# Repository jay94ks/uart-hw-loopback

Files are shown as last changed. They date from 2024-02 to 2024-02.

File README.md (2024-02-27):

## UART hardware loopback.
This hardware causes `UART` to loop back at the hardware level.
Developed based on the `STM32F042` and `CH340` chips, 
it taps the serial communication of the target software 
using the `baud-rate` auto-negotiation function of `VCP`.

In addition, since the pins of the 'SL2.1A' chip are left, 
so I added the USB hub function to utilize them.
and 'PD (Power Delivery)' input in case the current is insufficient.

### Hardware:
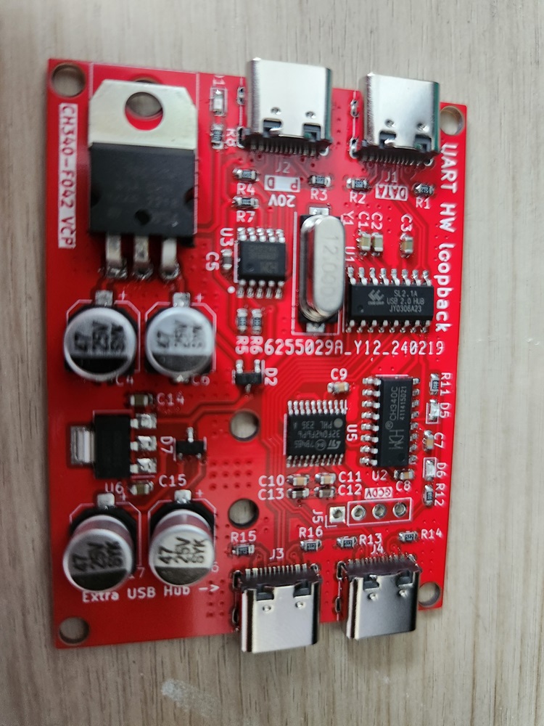
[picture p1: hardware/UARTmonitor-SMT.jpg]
Hardware


### Schematic:
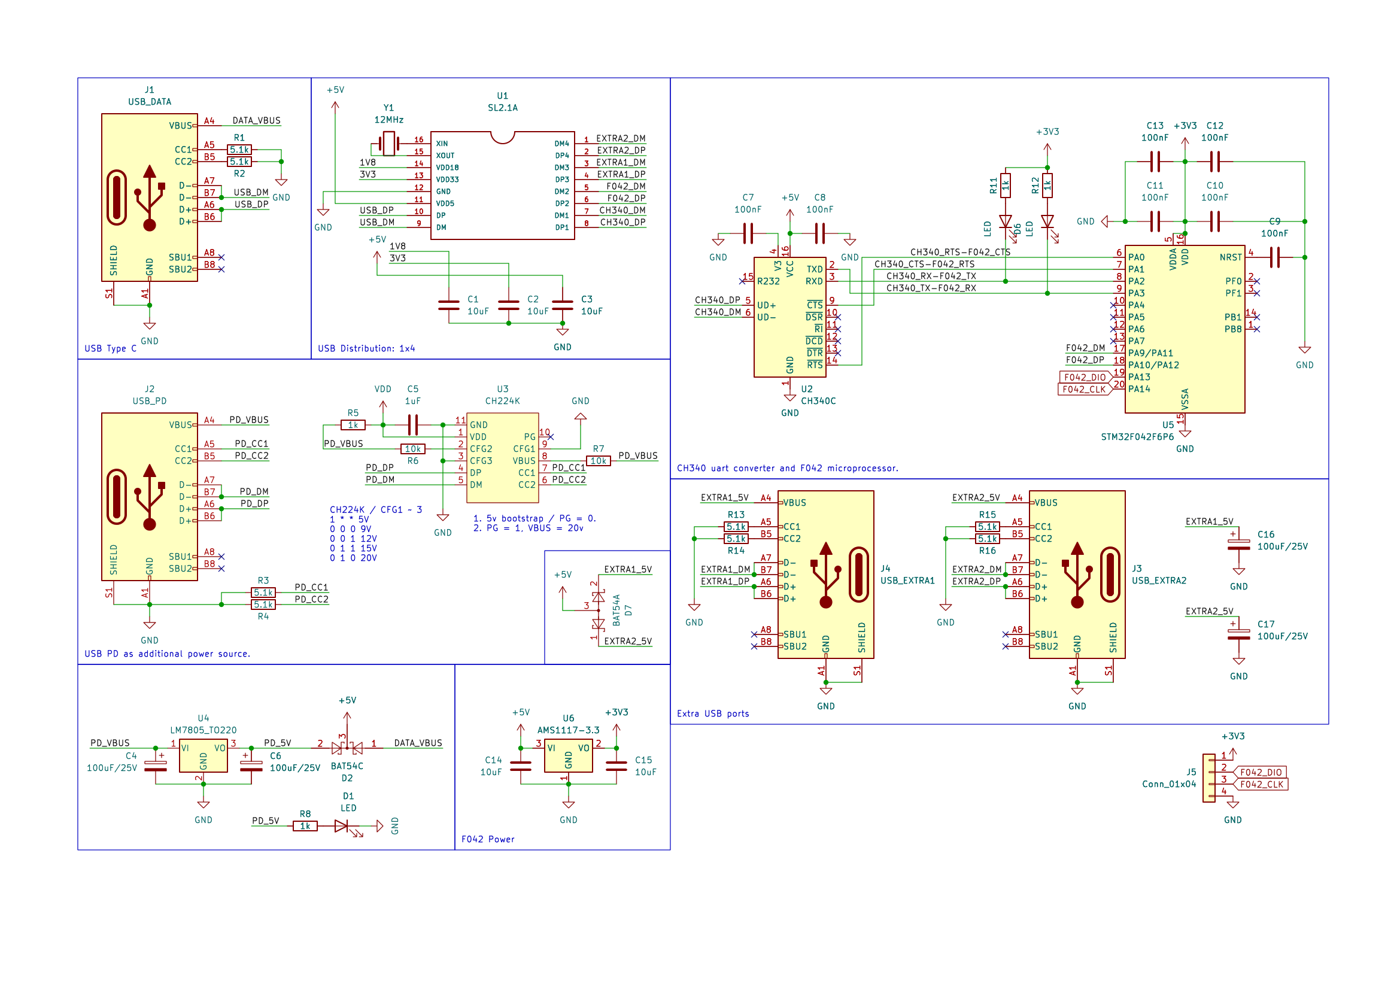
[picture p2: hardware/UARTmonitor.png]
Schematic


## How to connect:
### Requirements:
1. UART hardware loopback board with `USB Type-C` cable.
2. Target hardware and software.
3. This tapping software.

### Steps to configure the hardware:
1. Connect the data cable, `USB Type-C` to your PC,
2. Attach a `COM` port of `F042VCP` to target software.
3. Then, attach a `COM` port of `CH340` to this tapping software.
4. And, configure this tapping software to communicate with the target hardware.

## Flashing the firmware:
~~This board's `SL2.1A` USB hub chip seems like that disable the SWD pins.
(This seems to be a problem that occurs when the DP/DM pins wired on the board activate DFU mode or probe-like something)~~
So, you can flash the `F042F6P6` chip like:

### Set-up pull resistor to `BOOT0`.
This enables `ST-Link` SWD pins. if `BOOT0` pin is floating, the chip will never enable `DFU` or `SWD` pins.
* `BOOT0` -> pull down: enables `SWD`.
* `BOOT0` -> pull up: enables `DFU`.

### Using development board prototype.
Solder the `F042F6P6` chip to development board or use non-solder programming tools, and flash your chip, then re-solder it to this board. 

### `USB DFU` mode.
Initially, the `F042F6P6` chip will be booted in DFU mode.

1. download `DfuSe` tool from ST microelectronics website:
    https://www.st.com/content/my_st_com/en/products/development-tools/software-development-tools/stm32-software-development-tools/stm32-programmers/stsw-stm32080.licens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

2. install it and goto `[System drive]:\Program Files (x86)\STMicroelectronics\Software\DfuSe v3.0.6\Bin` using explorer.

3. double click `DfuFileMgr.exe`
4. check first option, `I want to GENERATE a DFU file from S19, HEX or BIN files` then click `next`.
5. put `DF11` to `Product ID` field.
6. click `S19 or Hex...` button then, select your built `HEX` file, and click `Generate`.
7. close `DFU File Manager` tool, and double click `DfuSeDemo.exe` file.
8. select `STM device in DFU mode` from `Available DFU Devices` combo box.
9. click `Choose...` button on `Upgrade or Verify Action` panel.
10. select `DFU` file that generated at 6th process, then click `Upgrade`.
11. finally, click `Leave DFU mode` on `Available DFU Devices` panel.
12. unplug your board and re-plug it.
13. done.

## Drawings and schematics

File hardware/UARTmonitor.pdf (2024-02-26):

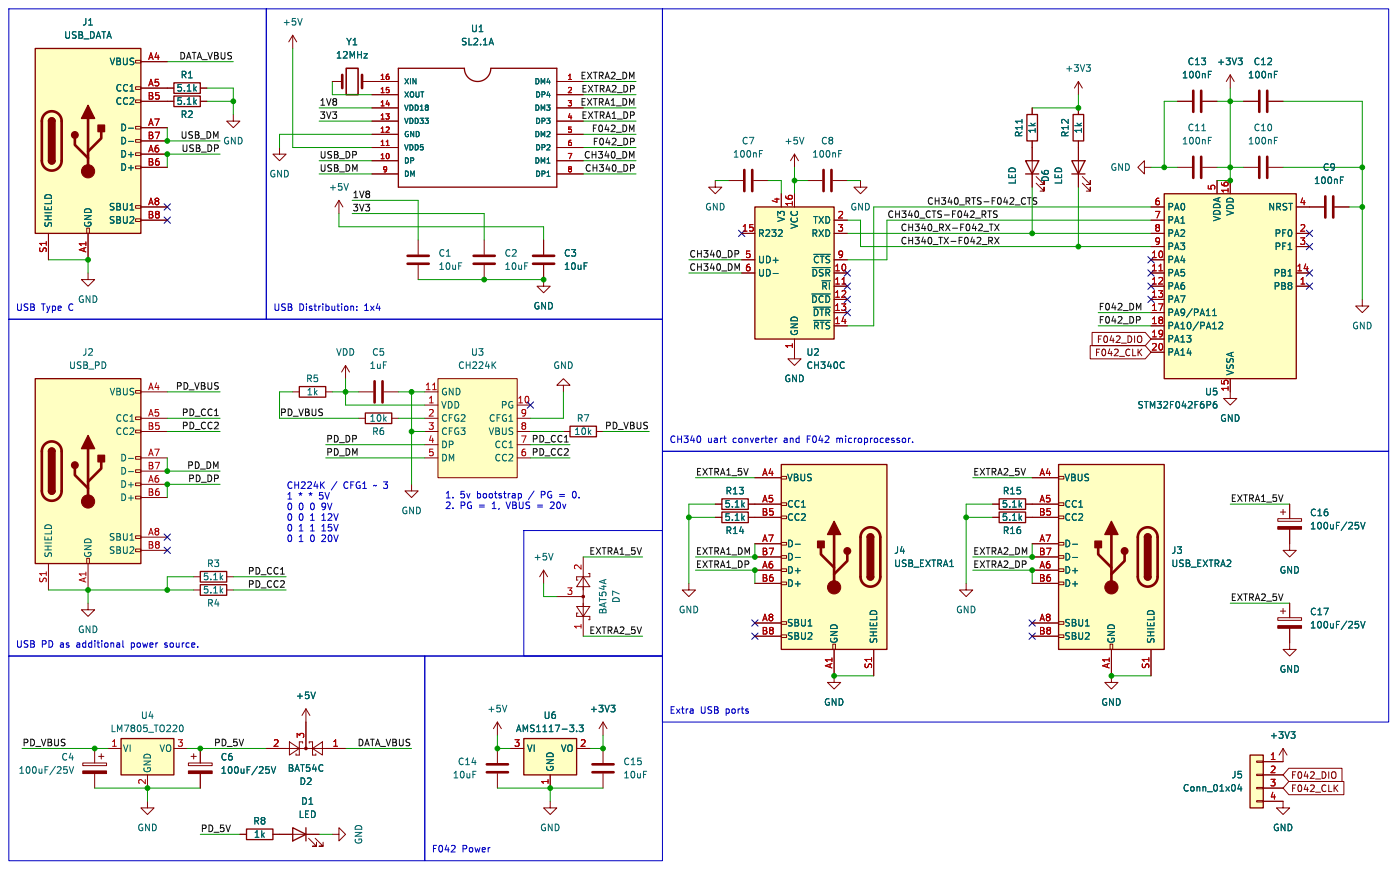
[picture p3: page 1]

1 ~{DSR} 10 ~{RI} 11 ~{DCD} 12 ~{DTR} 13 ~{RTS} 14 R232 15 VCC 16 TXD 2 RXD 3 V3

4 UD+ 5 UD- 6 ~{CTS}9 GND

1 VO 2 VI 3 U6 AMS1117-3.3 VI 1 GND
LM7805_TO220 GND

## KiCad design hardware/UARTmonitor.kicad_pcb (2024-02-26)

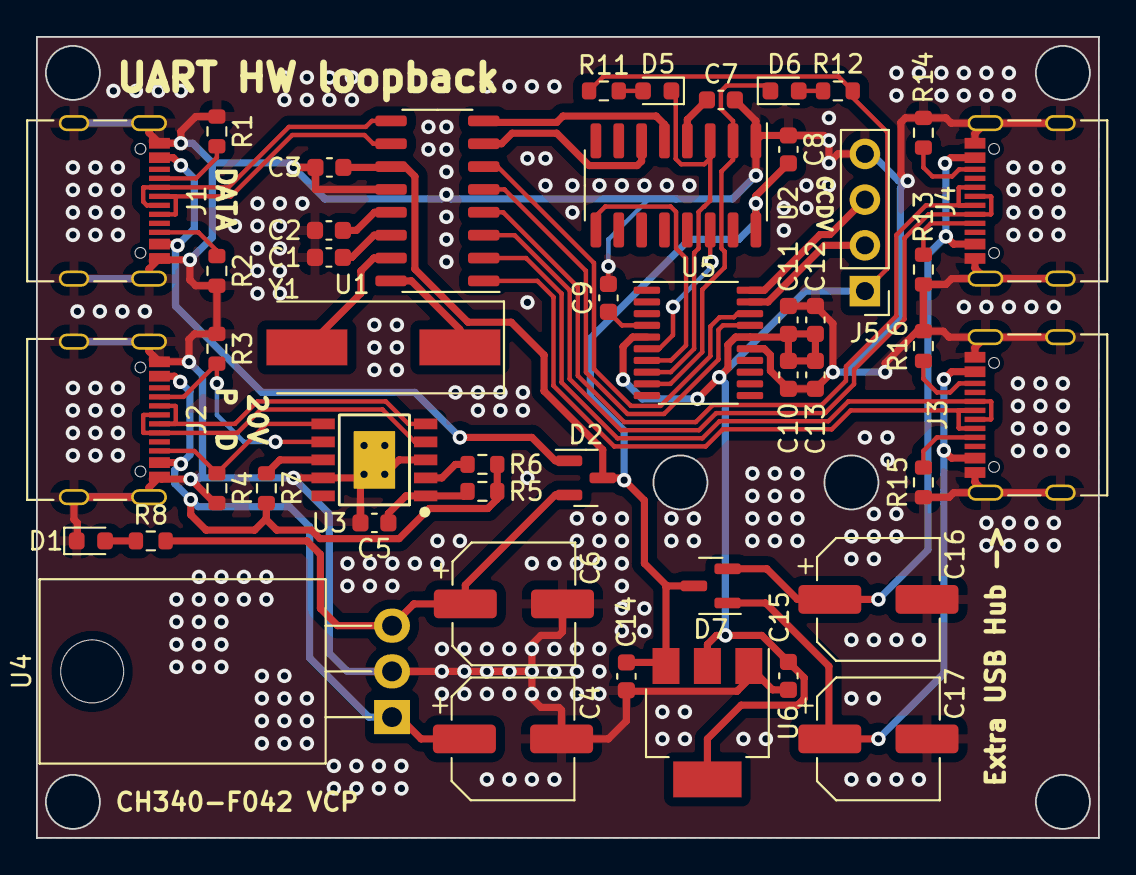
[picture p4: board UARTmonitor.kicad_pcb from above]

Board: 2 copper layers, 59.0 x 44.5 mm, 48 parts (0 on the bottom side), 46 nets.

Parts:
C1, C2, C3, C14, C15: 10uF; C_0603_1608Metric
C4, C6, C16, C17: 100uF/25V; CP_Elec_6.3x7.7
C5: 1uF; C_0603_1608Metric
C7, C8, C9, C10, C11, C12, C13: 100nF; C_0603_1608Metric
D1, D5, D6: LED; LED_0603_1608Metric
D2: BAT54C; SOT-23
D7: BAT54A; SOT-23
J1: USB_DATA; USB_C_Receptacle_Palconn_UTC16-G
J2: USB_PD; USB_C_Receptacle_Palconn_UTC16-G
J3: USB_EXTRA2; USB_C_Receptacle_Palconn_UTC16-G
J4: USB_EXTRA1; USB_C_Receptacle_Palconn_UTC16-G
J5: Conn_01x04; PinHeader_1x04_P2.54mm_Vertical
R1, R2, R3, R4, R13, R14, R15, R16: 5.1k; R_0603_1608Metric
R5, R8, R11, R12: 1k; R_0603_1608Metric
R6, R7: 10k; R_0603_1608Metric
U1: SL2.1A; SO-16_3.9x9.9mm_P1.27mm
U2: CH340C; SOIC-16_3.9x9.9mm_P1.27mm
U3: CH224K; ESSOP-10_CH224K
U4: LM7805_TO220; TO-220-3_Horizontal_TabDown
U5: STM32F042F6P6; TSSOP-20_4.4x6.5mm_P0.65mm
U6: AMS1117-3.3; SOT-223-3_TabPin2
Y1: 12MHz; Crystal_SMD_HC49-SD

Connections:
+3V3: C10.1, C11.1, C12.2, C13.1, C15.1, J5.1, R11.1, R12.1, U5.5 (VDDA), U5.16 (VDD), U6.2 (VO)
+5V: C3.1, C8.2, C14.1, D2.3, D7.3, U1.11 (VDD5), U2.16 (VCC), U6.3 (VI)
/1V8: C1.1, U1.14 (VDD18)
/3V3: C2.1, U1.13 (VDD33)
/CH340_CTS-F042_RTS: U2.9 (~CTS), U5.7 (PA1)
/CH340_DM: U1.7 (DM1), U2.6 (UD-)
/CH340_DP: U1.8 (DP1), U2.5 (UD+)
/CH340_RTS-F042_CTS: U2.14 (~RTS), U5.6 (PA0)
/CH340_RX-F042_TX: D5.1 (K), U2.3 (RXD), U5.8 (PA2)
/CH340_TX-F042_RX: D6.1 (K), U2.2 (TXD), U5.9 (PA3)
/DATA_VBUS: D2.1, J1.A4 (VBUS), J1.A9 (VBUS), J1.B4 (VBUS), J1.B9 (VBUS)
/EXTRA1_5V: C16.1, D7.2, J4.A4 (VBUS), J4.A9 (VBUS), J4.B4 (VBUS), J4.B9 (VBUS)
/EXTRA1_DM: J4.A7 (D-), J4.B7 (D-), U1.3 (DM3)
/EXTRA1_DP: J4.A6 (D+), J4.B6 (D+), U1.4 (DP3)
/EXTRA2_5V: C17.1, D7.1, J3.A4 (VBUS), J3.A9 (VBUS), J3.B4 (VBUS), J3.B9 (VBUS)
/EXTRA2_DM: J3.A7 (D-), J3.B7 (D-), U1.1 (DM4)
/EXTRA2_DP: J3.A6 (D+), J3.B6 (D+), U1.2 (DP4)
/F042_DM: U1.5 (DM2), U5.17 (PA9/PA11)
/F042_DP: U1.6 (DP2), U5.18 (PA10/PA12)
/PD_5V: C6.1, D2.2, R8.2, U4.3 (VO)
/PD_CC1: J2.A5 (CC1), R3.2, U3.7 (CC1)
/PD_CC2: J2.B5 (CC2), R4.1, U3.6 (CC2)
/PD_DM: J2.A7 (D-), J2.B7 (D-), U3.5 (DM)
/PD_DP: J2.A6 (D+), J2.B6 (D+), U3.4 (DP)
/PD_VBUS: C4.1, J2.A4 (VBUS), J2.A9 (VBUS), J2.B4 (VBUS), J2.B9 (VBUS), R5.1, R6.1, R7.2, U4.1 (VI)
/USB_DM: J1.A7 (D-), J1.B7 (D-), U1.9 (DM)
/USB_DP: J1.A6 (D+), J1.B6 (D+), U1.10 (DP)
F042_CLK: J5.3, U5.20 (PA14)
F042_DIO: J5.2, U5.19 (PA13)
GND: C1.2, C2.2, C3.2, C4.2, C5.2, C6.2, C7.2, C8.1, C9.2, C10.2, C11.2, C12.1, C13.2, C14.2, C15.2, C16.2, C17.2, D1.1 (K), J1.A1 (GND), J1.A12 (GND), J1.B1 (GND), J1.B12 (GND), J1.S1 (SHIELD), J2.A1 (GND), J2.A12 (GND), J2.B1 (GND), J2.B12 (GND), J2.S1 (SHIELD), J3.A1 (GND), J3.A12 (GND), J3.B1 (GND), J3.B12 (GND), J3.S1 (SHIELD), J4.A1 (GND), J4.A12 (GND), J4.B1 (GND), J4.B12 (GND), J4.S1 (SHIELD), J5.4, R1.1, R2.2, R3.1, R4.2, R13.1, R14.2, R15.1, R16.2, U1.12 (GND), U2.1 (GND), U3.3 (CFG3), U3.9 (CFG1), U3.11 (GND), U4.2 (GND), U5.15 (VSSA), U6.1 (GND)
unnamed: D1.2 (A), R8.1
unnamed: D5.2 (A), R11.2
unnamed: D6.2 (A), R12.2
unnamed: J1.A5 (CC1), R1.2
unnamed: J1.B5 (CC2), R2.1
unnamed: J3.A5 (CC1), R15.2
unnamed: J3.B5 (CC2), R16.1
unnamed: J4.A5 (CC1), R13.2
unnamed: J4.B5 (CC2), R14.1
unnamed: U1.16 (XIN), Y1.1
unnamed: U1.15 (XOUT), Y1.2
unnamed: C7.1, U2.4 (V3)
unnamed: R6.2, U3.2 (CFG2)
unnamed: R7.1, U3.8 (VBUS)
unnamed: C9.1, U5.4 (NRST)
VDD: C5.1, R5.2, U3.1 (VDD)

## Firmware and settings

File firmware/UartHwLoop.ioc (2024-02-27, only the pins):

Mcu.UserName=STM32F042F6Px
PA0.Signal=USART2_CTS
PA1.Signal=USART2_RTS
PA11.Signal=USB_DM
PA12.Signal=USB_DP
PA13.Signal=SYS_SWDIO
PA14.Signal=SYS_SWCLK
PA2.Signal=USART2_TX
PA3.Signal=USART2_RX

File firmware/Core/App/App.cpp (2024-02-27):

/*
 * App.cpp
 *
 *  Created on: Feb 27, 2024
 *      Author: jay94
 */

#include "main.h"
#include "usbd_cdc_if.h"

extern "C" {
	extern UART_HandleTypeDef huart2;

	uint8_t CDC_OnRxBytes(uint8_t* buf, uint32_t len) {
		if (HAL_UART_Transmit(&huart2, buf, len, 100 * len) != HAL_OK) {
			return 0;
		}

		return 1;
	}

	// --
	void runApp() {
		uint8_t temp[256] = { 0, };
		uint8_t pos = 0;

		while(true) {
			if (HAL_UART_Receive(&huart2, temp + pos, 1, 0) == HAL_OK) {
				if (++pos < sizeof(temp)) {
					continue;
				}
			}

			while(true) {
				auto ret = CDC_Transmit_FS(temp, pos);
				if (ret != USBD_OK) {
					continue;
				}

				break;
			}

			pos = 0;
		}
	}


}

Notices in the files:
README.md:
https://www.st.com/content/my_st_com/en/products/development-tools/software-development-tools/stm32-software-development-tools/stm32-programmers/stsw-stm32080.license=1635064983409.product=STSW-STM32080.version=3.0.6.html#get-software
